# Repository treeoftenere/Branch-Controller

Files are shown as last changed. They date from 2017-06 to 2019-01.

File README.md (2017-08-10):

# Branch-Controller

The branch controllers are running on STM32 Bluepill boards with a wiznet w5500 based ethernet module.

The branch controller depends on the following:
1. Arduino support for STM32F1  ** master? **
2. FastLED with support for STM32F1  ** Currently uses Tenere Branch **
3. Ethernet library, based on the teensy implementation with faster settings  ** master? **

## Arduino settings:
Board:  Generic STM32F103C
Upload Method:  JLink

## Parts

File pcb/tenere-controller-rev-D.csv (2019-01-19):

Part/Designator | Description | MPN | Quantity
C1,C2,C3,C4,C5,C6,C7,C8 | Cap 1206 100uF | GRM31CD80J107ME39L | 8
C9,C10 | Cap 0603 10uF | CL10A106MQ8NNNC | 2
C11,C12 | Cap 0603 0.1uF | CL10B104KO8NNNC | 2
J1,J2,J3,J4,J5,J6,J7,J8 | 4 pin connector | 43650-0400 | 8
J10 | 8 pin DIP switch | BPA08B | 1
R1,R2,R3,R4,R5,R6,R7,R8,R9,R10,R11,R12,R13,R14,R15,R16 | Resistor 0603 22R | RC0603JR-0733RL | 16
SW1 | Tact switch | 1-1825027-1 | 1
U1 | STM32 module | STM32 module | 1
U2,U3 | 8 bit line driver | 74HCT245PW,118 | 2
U4 | 3.3V LDO | LD1117S33TR | 1
U5 | Ethernet module | Ethernet module | 1

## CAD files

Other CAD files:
enclosure/VG-S05.dwg

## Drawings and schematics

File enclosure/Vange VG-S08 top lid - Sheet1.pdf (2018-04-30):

G | G
H | H

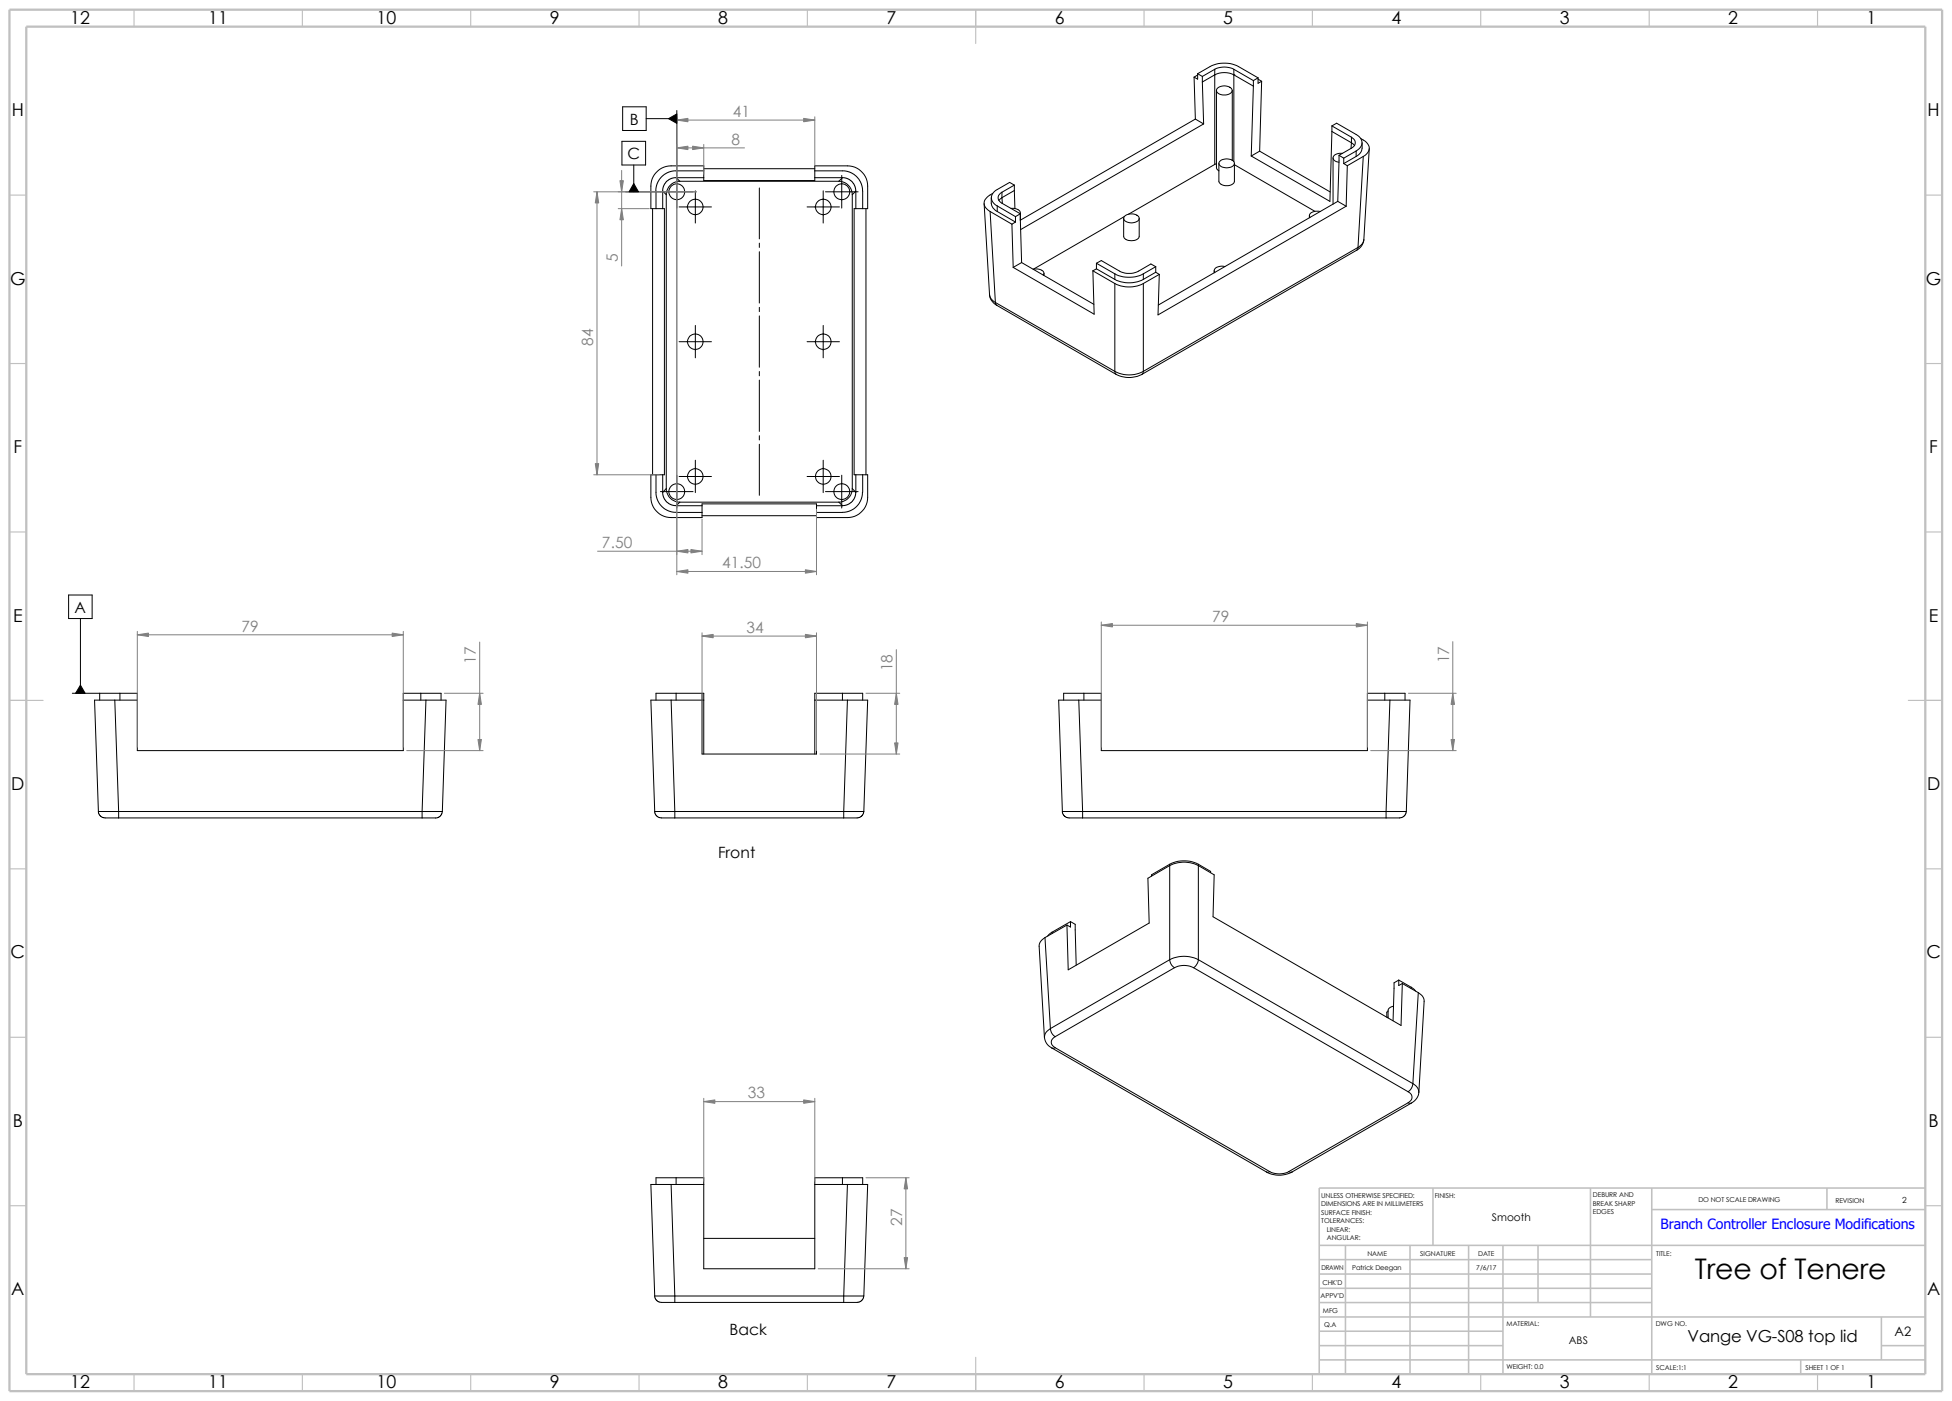
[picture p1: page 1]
Back; ABS; SHEET 1 OF 1; SCALE:1:1; MFG; FINISH:; EDGES; MATERIAL:; Smooth; REVISION; WEIGHT: 0.0; DEBURR AND; BREAK SHARP; Front

UNLESS OTHERWISE SPECIFIED:
DIMENSIONS ARE IN MILLIMETERS
SURFACE FINISH:
TOLERANCES:
LINEAR:
ANGULAR:

DO NOT SCALE DRAWING
Branch Controller Enclosure Modifications

NAME | SIGNATURE | DATE | TITLE: Tree of Tenere

DRAWN | Patrick Deegan | | 7/6/17

CHK'D

APPV'D

DWG NO.
Vange VG-S08 top lid

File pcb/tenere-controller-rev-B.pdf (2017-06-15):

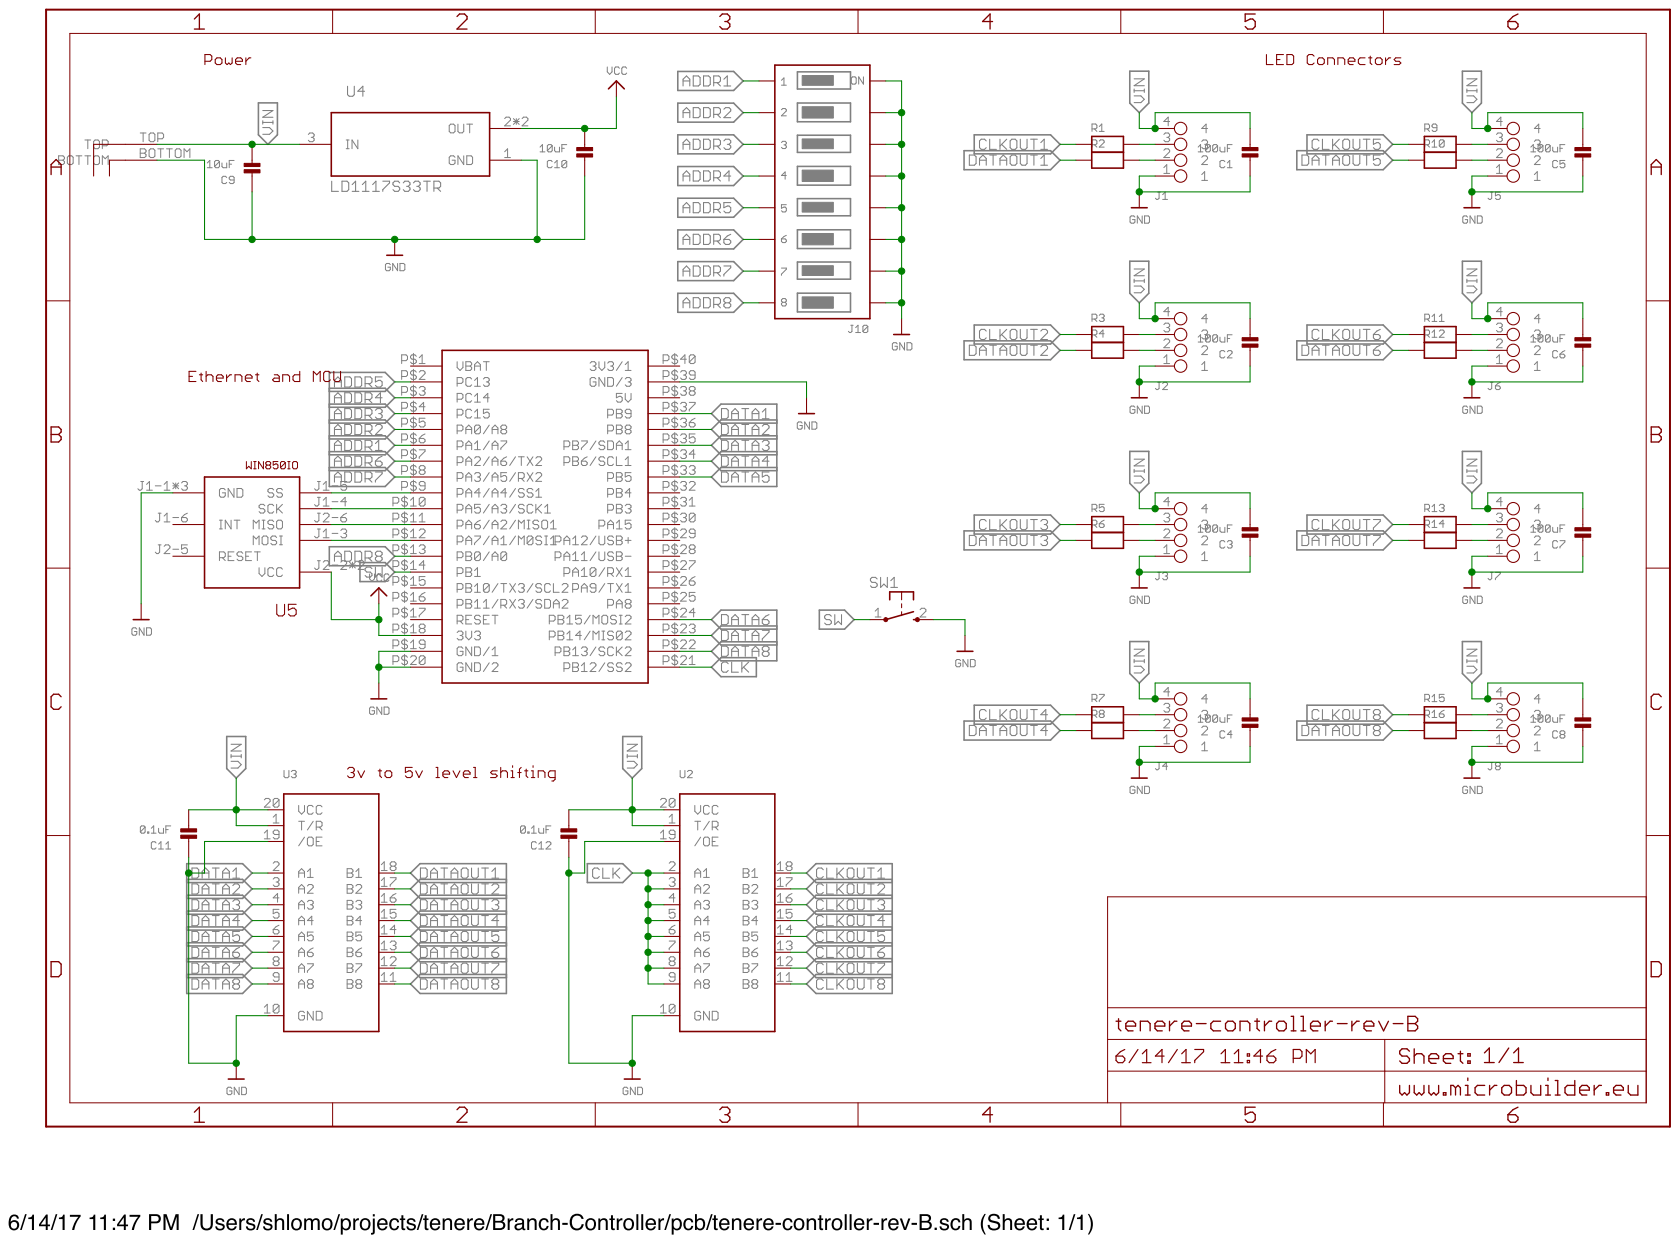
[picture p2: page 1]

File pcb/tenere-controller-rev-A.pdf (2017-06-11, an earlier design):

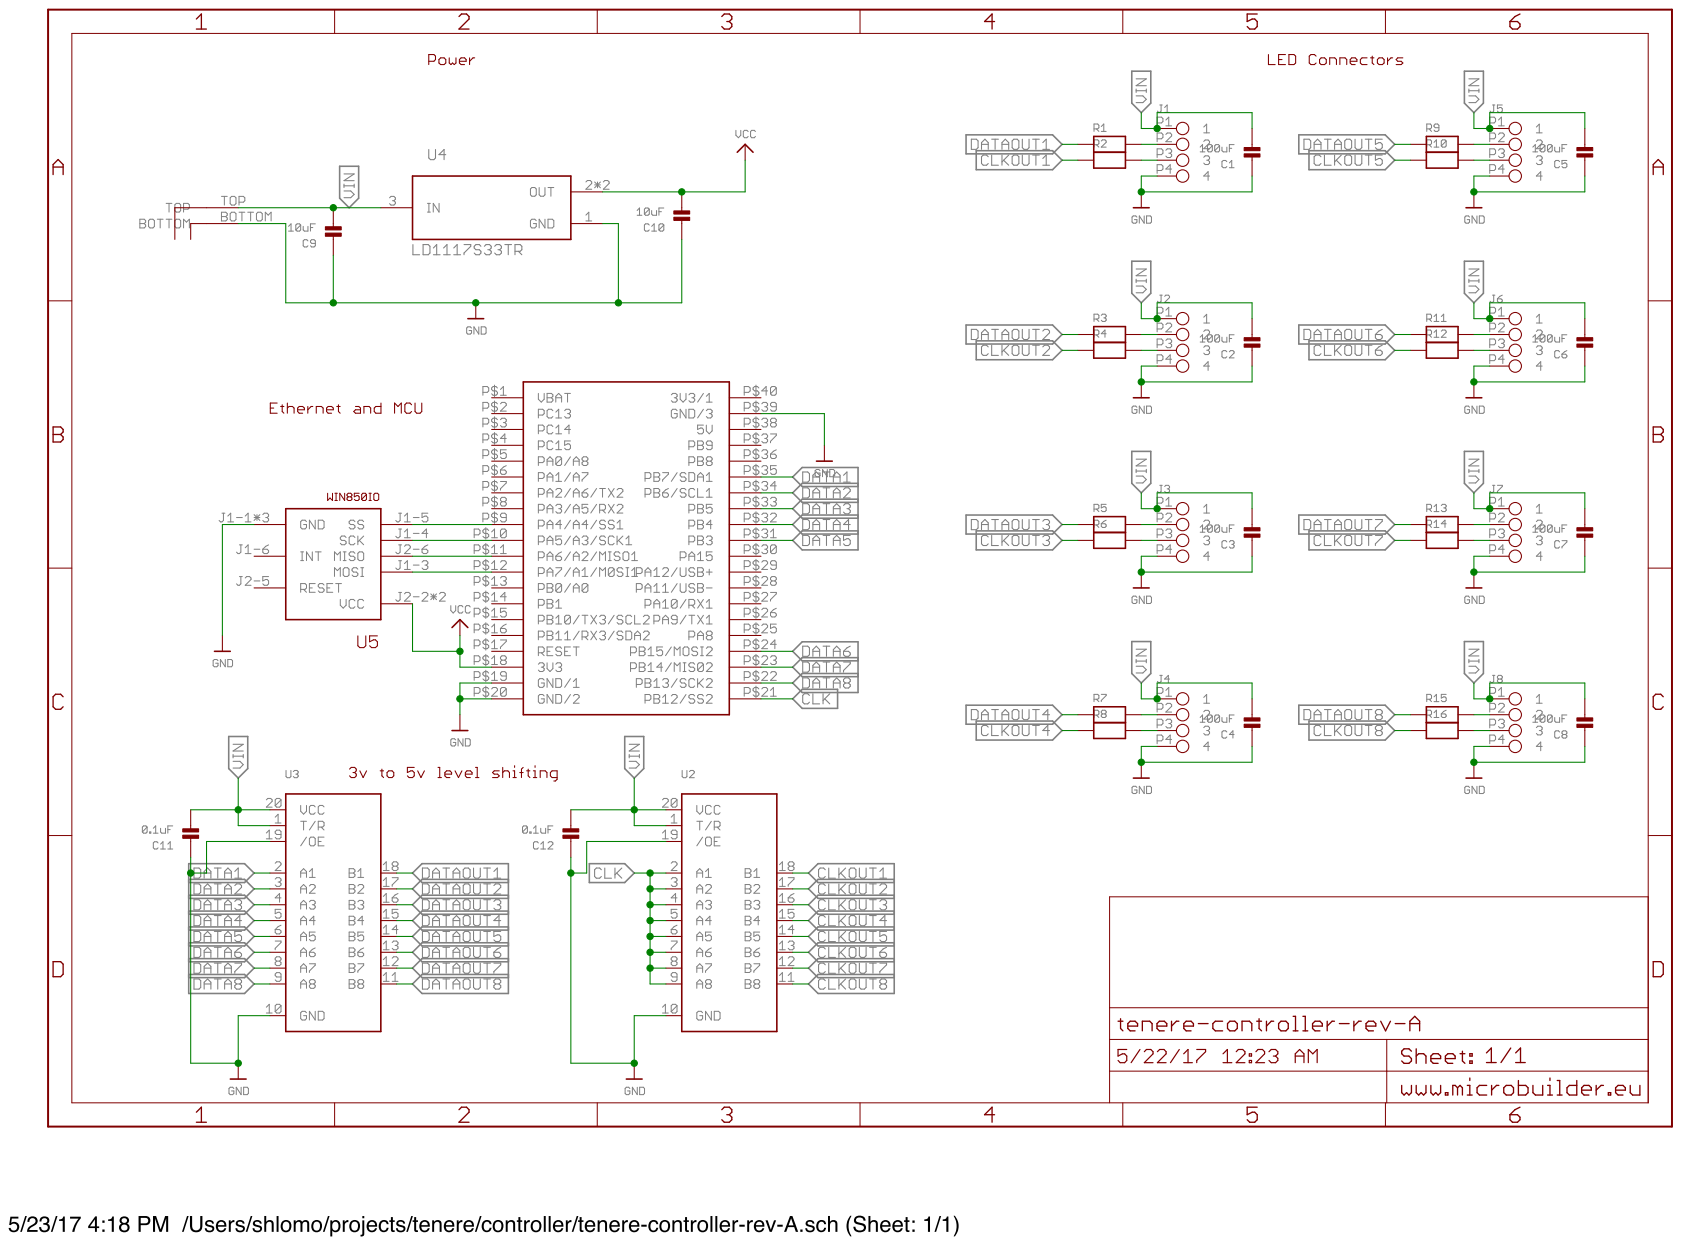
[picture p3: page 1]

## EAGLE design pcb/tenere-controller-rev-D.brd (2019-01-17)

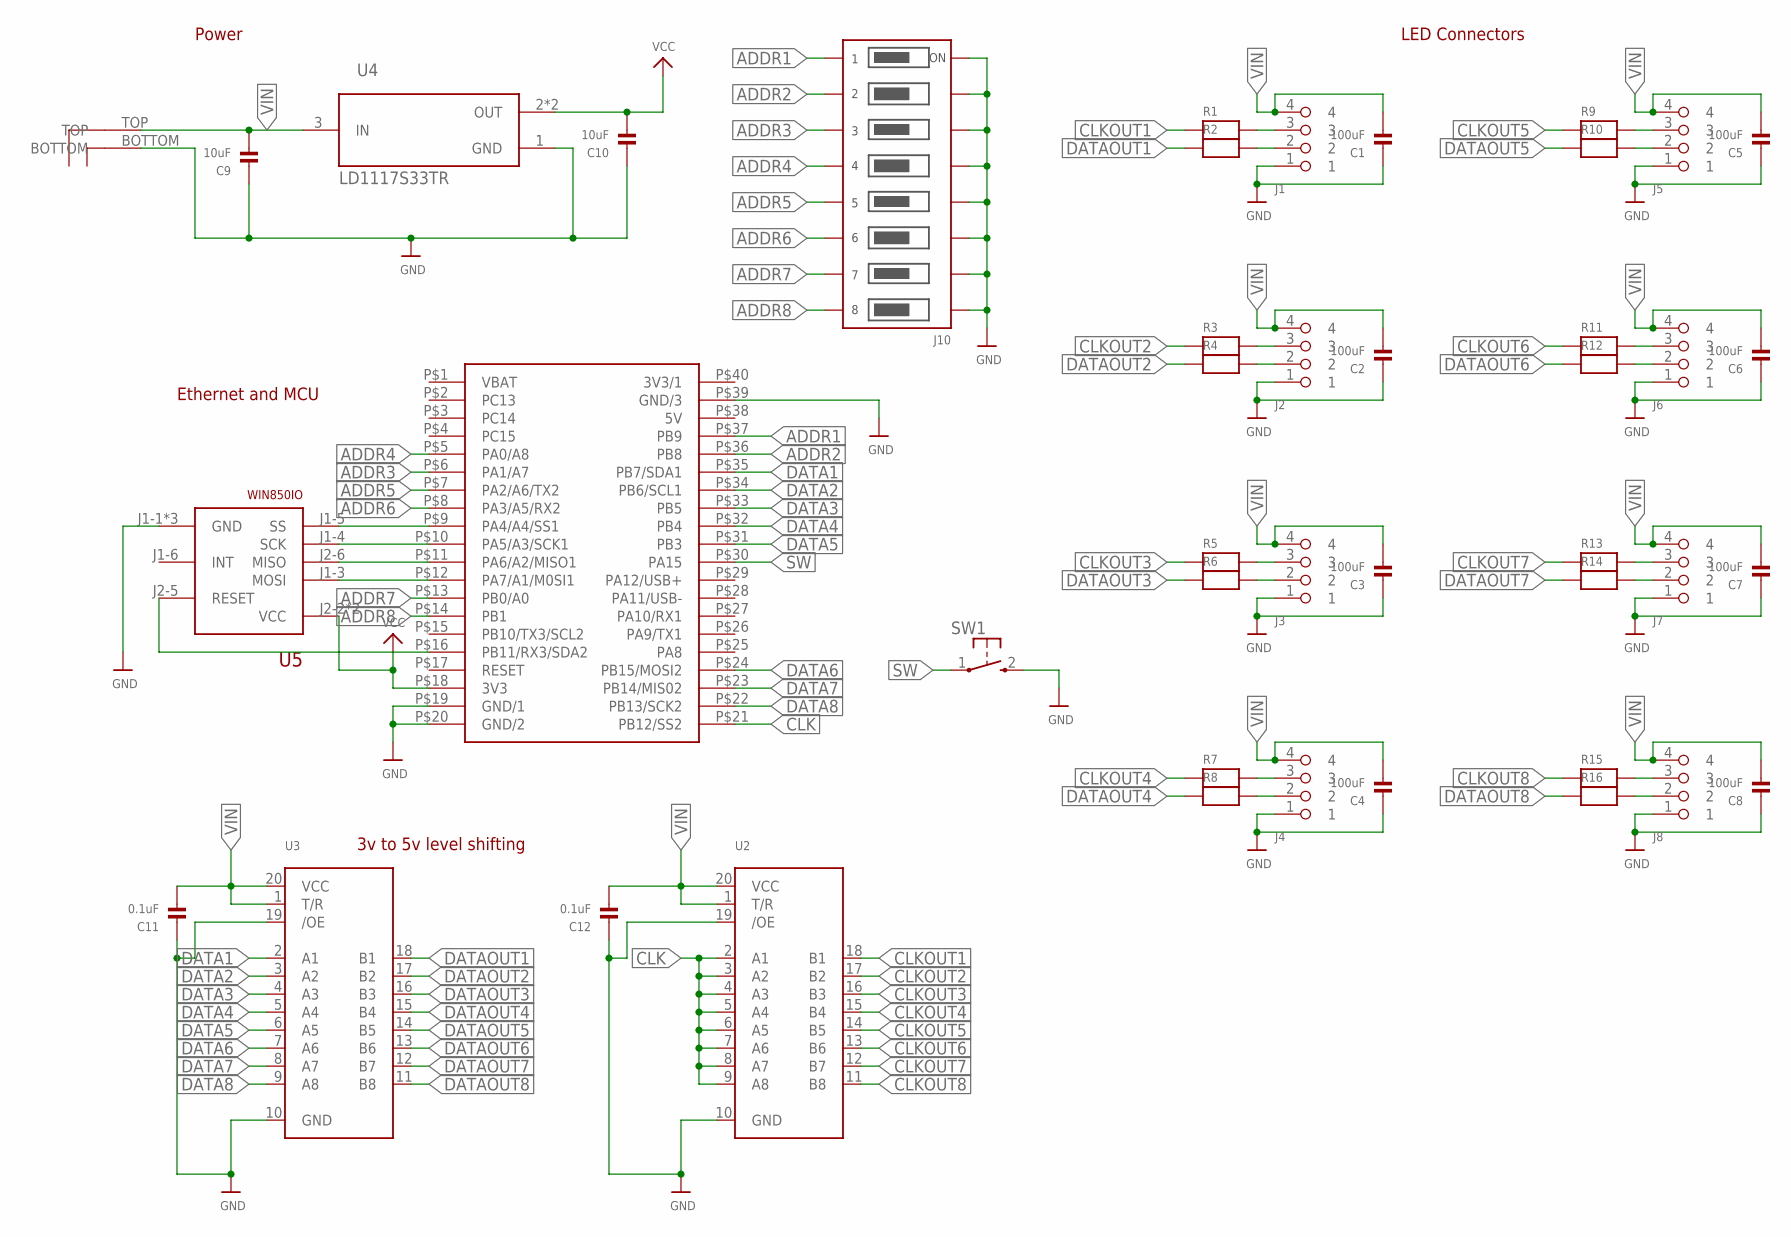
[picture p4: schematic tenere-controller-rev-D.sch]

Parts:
C1, C2, C3, C4, C5, C6, C7, C8: 100uF; 1206
C9, C10: 10uF; 0603
C11, C12: 0.1uF; 0603
J1, J2, J3, J4, J5, J6, J7, J8: MICROFIT3; 43650-0400
J9: POWERPOLE-2V; POWERPOLE_STACKED
J10: DIP-SWITCH-8PIN; BPA08B
R1, R2, R3, R4, R5, R6, R7, R8, R9, R10, R11, R12, R13, R14, R15, R16: RESISTOR0603; 0603
SW1: TACTILE-SWITCH-1825027; 1825027
U1: BLUEPILL; 40-DIP-BLUE-PIL
U2, U3: 74LCX245; TSSOP20
U4: LD1117S33TR; LD1117S33TR_SOT230P700X180-4N
U5: WIN850IO; WIZ850IO

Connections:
ADDR1: J10.1' (1B), U1.P$37 (PB9)
ADDR2: J10.2' (2B), U1.P$36 (PB8)
ADDR3: J10.3' (3B), U1.P$6 (PA1/A7)
ADDR4: J10.4' (4B), U1.P$5 (PA0/A8)
ADDR5: J10.5' (5B), U1.P$7 (PA2/A6/TX2)
ADDR6: J10.6' (6B), U1.P$8 (PA3/A5/RX2)
ADDR7: J10.7' (7B), U1.P$13 (PB0/A0)
ADDR8: J10.8' (8B), U1.P$14 (PB1)
CLK: U1.P$21 (PB12/SS2), U2.2 (A1), U2.3 (A2), U2.4 (A3), U2.5 (A4), U2.6 (A5), U2.7 (A6), U2.8 (A7), U2.9 (A8)
CLKOUT1: R1.1, U2.18 (B1)
CLKOUT2: R3.1, U2.17 (B2)
CLKOUT3: R5.1, U2.16 (B3)
CLKOUT4: R7.1, U2.15 (B4)
CLKOUT5: R9.1, U2.14 (B5)
CLKOUT6: R11.1, U2.13 (B6)
CLKOUT7: R13.1, U2.12 (B7)
CLKOUT8: R15.1, U2.11 (B8)
DATA1: U1.P$35 (PB7/SDA1), U3.2 (A1)
DATA2: U1.P$34 (PB6/SCL1), U3.3 (A2)
DATA3: U1.P$33 (PB5), U3.4 (A3)
DATA4: U1.P$32 (PB4), U3.5 (A4)
DATA5: U1.P$31 (PB3), U3.6 (A5)
DATA6: U1.P$24 (PB15/MOSI2), U3.7 (A6)
DATA7: U1.P$23 (PB14/MIS02), U3.8 (A7)
DATA8: U1.P$22 (PB13/SCK2), U3.9 (A8)
DATAOUT1: R2.1, U3.18 (B1)
DATAOUT2: R4.1, U3.17 (B2)
DATAOUT3: R6.1, U3.16 (B3)
DATAOUT4: R8.1, U3.15 (B4)
DATAOUT5: R10.1, U3.14 (B5)
DATAOUT6: R12.1, U3.13 (B6)
DATAOUT7: R14.1, U3.12 (B7)
DATAOUT8: R16.1, U3.11 (B8)
GND: C1.1, C2.1, C3.1, C4.1, C5.1, C6.1, C7.1, C8.1, C9.1, C10.1, C11.1, C12.1, J1.1, J2.1, J3.1, J4.1, J5.1, J6.1, J7.1, J8.1, J9.BOTTOM, J10.1 (1A), J10.2 (2A), J10.3 (3A), J10.4 (4A), J10.5 (5A), J10.6 (6A), J10.7 (7A), J10.8 (8A), SW1.2 (3), U1.P$19 (GND/1), U1.P$20 (GND/2), U1.P$39 (GND/3), U2.10 (GND), U2.19 (/OE), U3.10 (GND), U3.19 (/OE), U4.1 (GND), U5.J1-1 (GND), U5.J1-2 (GND), U5.J2-1 (GND)
unnamed: U1.P$9 (PA4/A4/SS1), U5.J1-5 (SS)
unnamed: U1.P$10 (PA5/A3/SCK1), U5.J1-4 (SCK)
unnamed: U1.P$11 (PA6/A2/MISO1), U5.J2-6 (MISO)
unnamed: U1.P$12 (PA7/A1/M0SI1), U5.J1-3 (MOSI)
unnamed: J1.3, R1.2
unnamed: J1.2, R2.2
unnamed: J2.3, R3.2
unnamed: J2.2, R4.2
unnamed: J3.3, R5.2
unnamed: J3.2, R6.2
unnamed: J4.3, R7.2
unnamed: J4.2, R8.2
unnamed: J5.3, R9.2
unnamed: J5.2, R10.2
unnamed: J6.3, R11.2
unnamed: J6.2, R12.2
unnamed: J7.3, R13.2
unnamed: J7.2, R14.2
unnamed: J8.3, R15.2
unnamed: J8.2, R16.2
unnamed: U1.P$16 (PB11/RX3/SDA2), U5.J2-5 (RESET)
SW: SW1.1, U1.P$30 (PA15)
VCC: C10.2, U1.P$18 (3V3), U4.2 (OUT), U4.4 (OUT), U5.J2-2 (VCC), U5.J2-3 (VCC)
VIN: C1.2, C2.2, C3.2, C4.2, C5.2, C6.2, C7.2, C8.2, C9.2, C11.2, C12.2, J1.4, J2.4, J3.4, J4.4, J5.4, J6.4, J7.4, J8.4, J9.TOP, U2.1 (T/R), U2.20 (VCC), U3.1 (T/R), U3.20 (VCC), U4.3 (IN)

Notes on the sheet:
LED Connectors
Power
Ethernet and MCU
3v to 5v level shifting

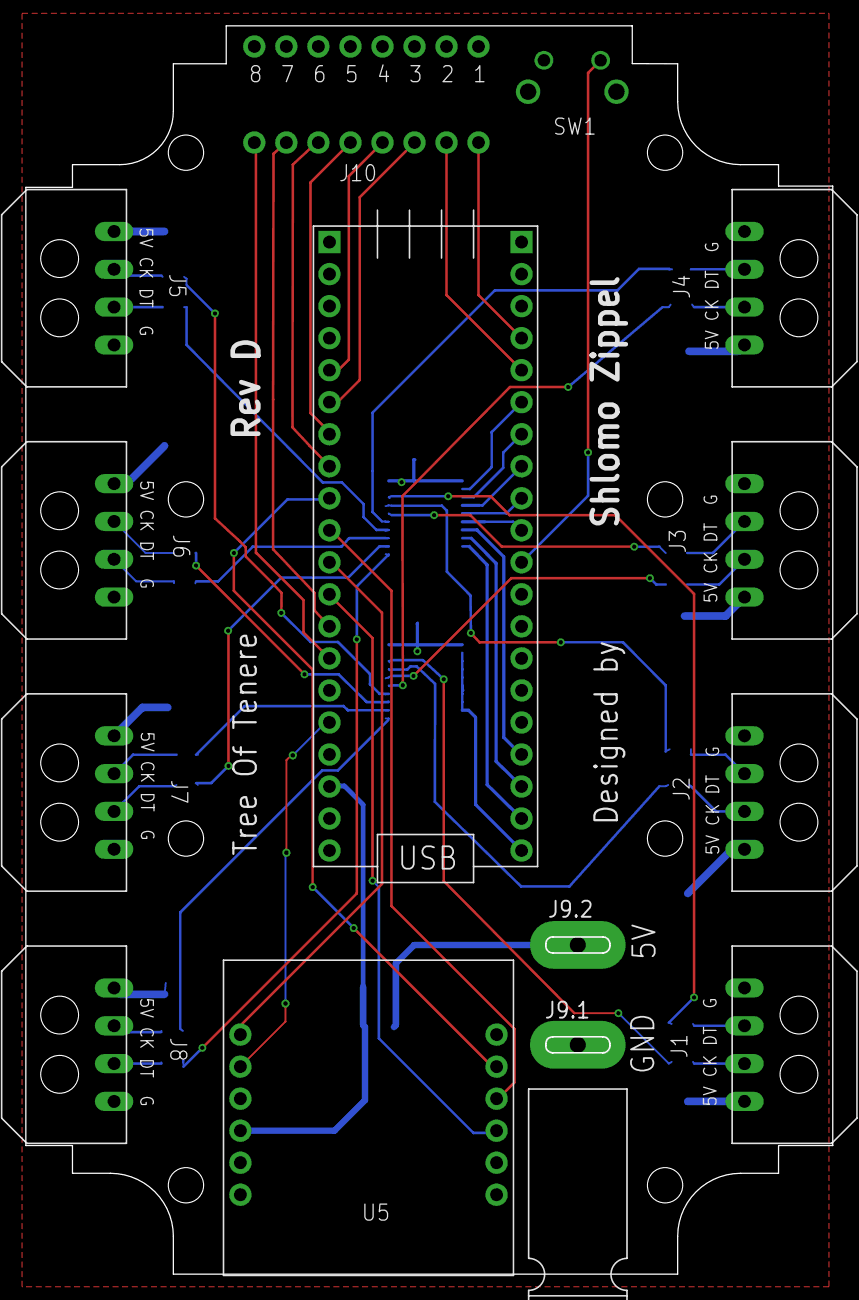
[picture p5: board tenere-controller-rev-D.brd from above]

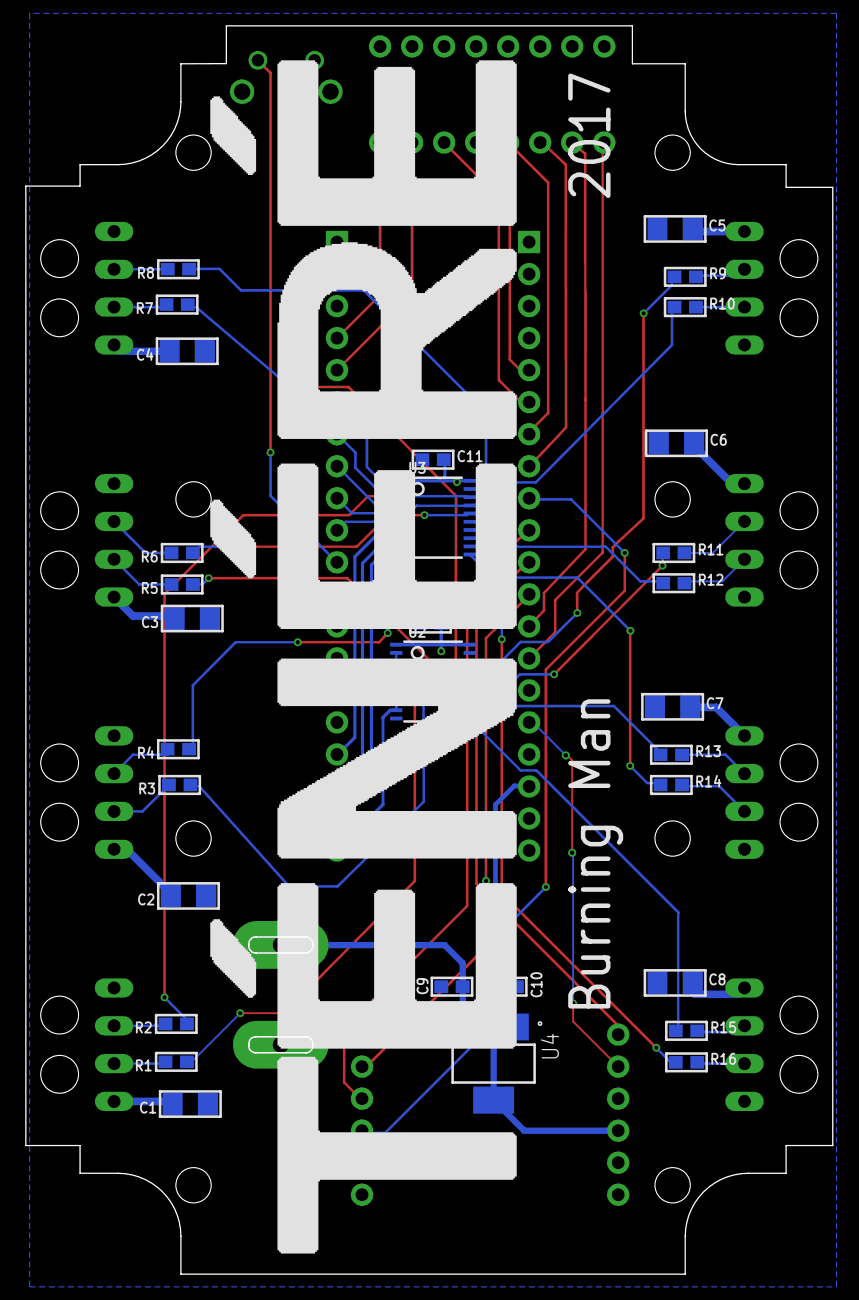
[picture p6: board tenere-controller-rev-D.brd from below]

Board: 2 copper layers, 64.0 x 99.0 mm, 45 parts (31 on the bottom side), 58 nets.

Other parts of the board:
U$15: 105*65

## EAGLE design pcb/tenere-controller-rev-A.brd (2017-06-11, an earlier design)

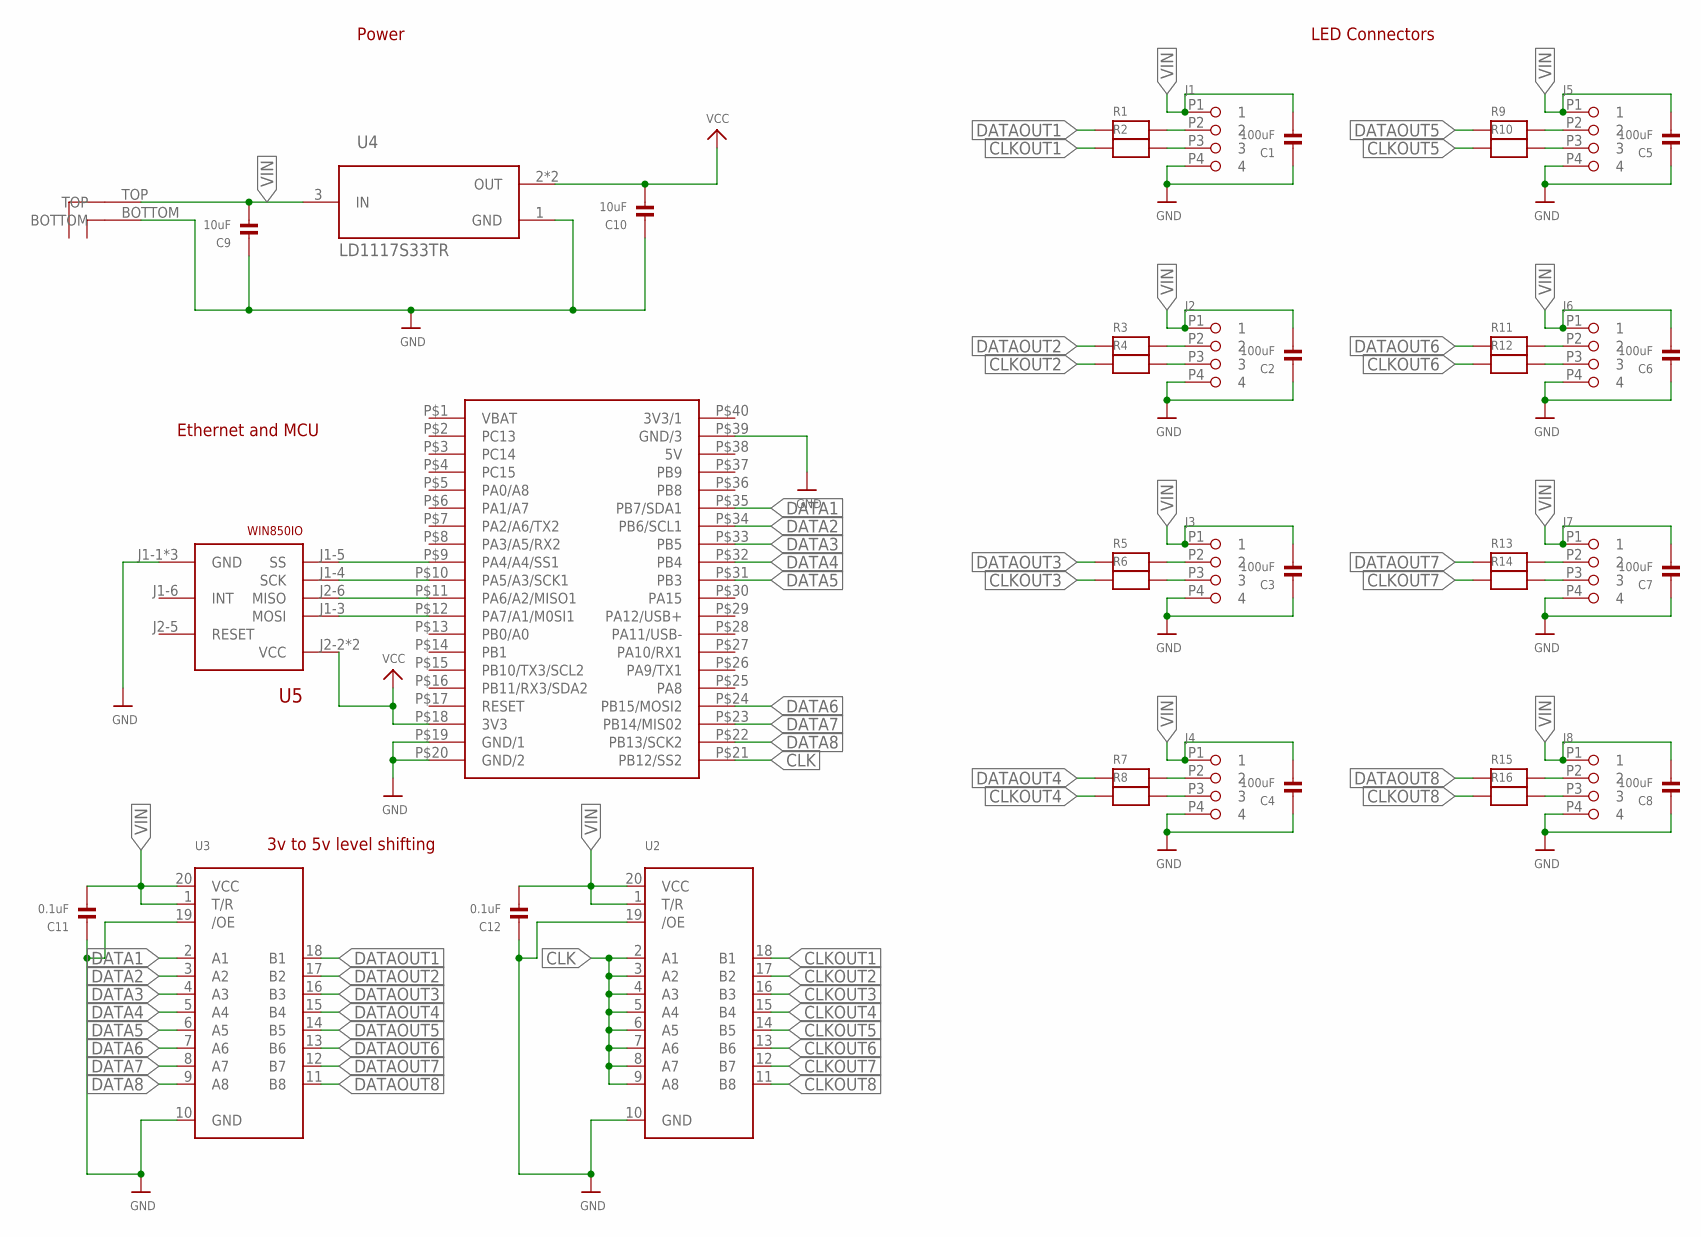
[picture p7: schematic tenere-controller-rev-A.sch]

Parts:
C1, C2, C3, C4, C5, C6, C7, C8: 100uF; 1206
C9, C10: 10uF; 0603
C11, C12: 0.1uF; 0603
J1, J2, J3, J4, J5, J6, J7, J8: JST-XH-4P-SODE; JST-XH-BS4P
J9: POWERPOLE-2V; POWERPOLE_STACKED
R1, R2, R3, R4, R5, R6, R7, R8, R9, R10, R11, R12, R13, R14, R15, R16: RESISTOR0603; 0603
U1: BLUEPILL; 40-DIP-BLUE-PIL
U2, U3: 74LCX245; TSSOP20
U4: LD1117S33TR; LD1117S33TR_SOT230P700X180-4N
U5: WIN850IO; WIZ850IO

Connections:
CLK: U1.P$21 (PB12/SS2), U2.2 (A1), U2.3 (A2), U2.4 (A3), U2.5 (A4), U2.6 (A5), U2.7 (A6), U2.8 (A7), U2.9 (A8)
CLKOUT1: R2.1, U2.18 (B1)
CLKOUT2: R4.1, U2.17 (B2)
CLKOUT3: R6.1, U2.16 (B3)
CLKOUT4: R8.1, U2.15 (B4)
CLKOUT5: R10.1, U2.14 (B5)
CLKOUT6: R12.1, U2.13 (B6)
CLKOUT7: R14.1, U2.12 (B7)
CLKOUT8: R16.1, U2.11 (B8)
DATA1: U1.P$35 (PB7/SDA1), U3.2 (A1)
DATA2: U1.P$34 (PB6/SCL1), U3.3 (A2)
DATA3: U1.P$33 (PB5), U3.4 (A3)
DATA4: U1.P$32 (PB4), U3.5 (A4)
DATA5: U1.P$31 (PB3), U3.6 (A5)
DATA6: U1.P$24 (PB15/MOSI2), U3.7 (A6)
DATA7: U1.P$23 (PB14/MIS02), U3.8 (A7)
DATA8: U1.P$22 (PB13/SCK2), U3.9 (A8)
DATAOUT1: R1.1, U3.18 (B1)
DATAOUT2: R3.1, U3.17 (B2)
DATAOUT3: R5.1, U3.16 (B3)
DATAOUT4: R7.1, U3.15 (B4)
DATAOUT5: R9.1, U3.14 (B5)
DATAOUT6: R11.1, U3.13 (B6)
DATAOUT7: R13.1, U3.12 (B7)
DATAOUT8: R15.1, U3.11 (B8)
GND: C1.1, C2.1, C3.1, C4.1, C5.1, C6.1, C7.1, C8.1, C9.1, C10.1, C11.1, C12.1, J1.P4 (4), J2.P4 (4), J3.P4 (4), J4.P4 (4), J5.P4 (4), J6.P4 (4), J7.P4 (4), J8.P4 (4), J9.BOTTOM, U1.P$19 (GND/1), U1.P$20 (GND/2), U1.P$39 (GND/3), U2.10 (GND), U2.19 (/OE), U3.10 (GND), U3.19 (/OE), U4.1 (GND), U5.J1-1 (GND), U5.J1-2 (GND), U5.J2-1 (GND)
unnamed: U1.P$9 (PA4/A4/SS1), U5.J1-5 (SS)
unnamed: U1.P$10 (PA5/A3/SCK1), U5.J1-4 (SCK)
unnamed: U1.P$11 (PA6/A2/MISO1), U5.J2-6 (MISO)
unnamed: U1.P$12 (PA7/A1/M0SI1), U5.J1-3 (MOSI)
unnamed: J1.P2 (2), R1.2
unnamed: J1.P3 (3), R2.2
unnamed: J2.P2 (2), R3.2
unnamed: J2.P3 (3), R4.2
unnamed: J3.P2 (2), R5.2
unnamed: J3.P3 (3), R6.2
unnamed: J4.P2 (2), R7.2
unnamed: J4.P3 (3), R8.2
unnamed: J5.P2 (2), R9.2
unnamed: J5.P3 (3), R10.2
unnamed: J6.P2 (2), R11.2
unnamed: J6.P3 (3), R12.2
unnamed: J7.P2 (2), R13.2
unnamed: J7.P3 (3), R14.2
unnamed: J8.P2 (2), R15.2
unnamed: J8.P3 (3), R16.2
VCC: C10.2, U1.P$18 (3V3), U4.2 (OUT), U4.4 (OUT), U5.J2-2 (VCC), U5.J2-3 (VCC)
VIN: C1.2, C2.2, C3.2, C4.2, C5.2, C6.2, C7.2, C8.2, C9.2, C11.2, C12.2, J1.P1 (1), J2.P1 (1), J3.P1 (1), J4.P1 (1), J5.P1 (1), J6.P1 (1), J7.P1 (1), J8.P1 (1), J9.TOP, U2.1 (T/R), U2.20 (VCC), U3.1 (T/R), U3.20 (VCC), U4.3 (IN)

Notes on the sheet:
LED Connectors
Power
Ethernet and MCU
3v to 5v level shifting

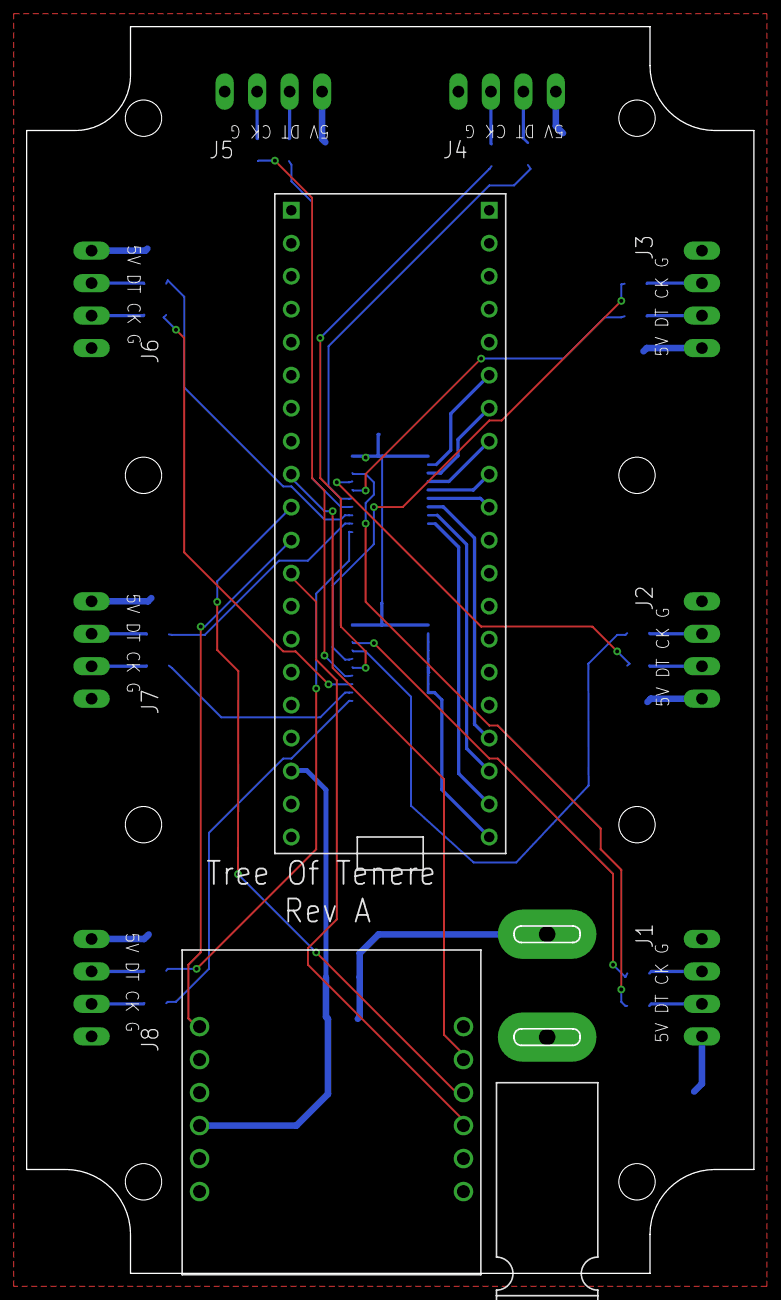
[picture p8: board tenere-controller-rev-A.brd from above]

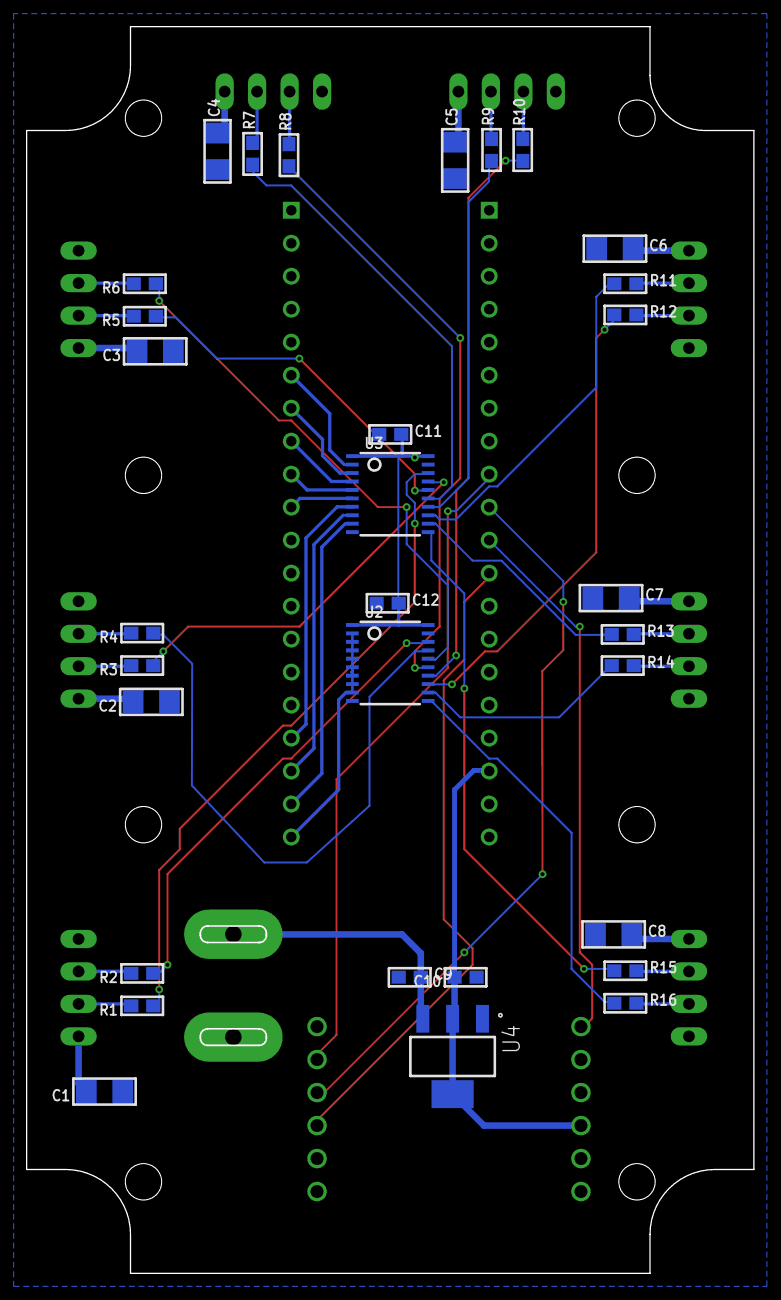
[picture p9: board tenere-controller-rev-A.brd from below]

Board: 2 copper layers, 56.0 x 96.0 mm, 43 parts (31 on the bottom side), 48 nets.

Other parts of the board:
U$15: 105*65

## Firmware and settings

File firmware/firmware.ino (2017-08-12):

#include <SPI.h>
#include <Ethernet.h>
#include <FastLED.h>
#include <EEPROM.h>
#include "button.h"

#define LEDS_PER_CHANNEL    105
#define NUM_CHANNELS        8
#define NUM_LEDS            (NUM_CHANNELS * LEDS_PER_CHANNEL)
#define COLOR_ORDER         BGR
#define SPI_RATE            DATA_RATE_MHZ(4)
#define UDP_RX_BUFFER_SIZE  8192
#define UDP_PORT_NUMBER     1337

#define PARALLEL_OUTPUT
#define PLAYA_MODE

//-------------------------------------------------------------------------------------------
// Pin mappings
//-------------------------------------------------------------------------------------------

//#define REVB
#define REVC

#ifdef REVB
uint8_t dip_switch_pins[] = {PA0, PA1, PA2, PA3, PB0};
#define SWITCH_PIN  PB1
#endif 

#ifdef REVC
uint8_t dip_switch_pins[] = {PB9, PB8, PA1, PA0, PA2, PA3, PB0, PB1};
#define SWITCH_PIN  PA15
#endif

#define FPS_PIN         PA0
#define CLOCK_PIN       PB12
#define ETHERNET_CS_PIN PA4
#define INDICATOR_PIN   PC13

#define ARRAY_SIZE(A) (sizeof(A) / sizeof((A)[0]))

CRGB leds[NUM_CHANNELS][LEDS_PER_CHANNEL];

typedef struct _opc_header_t {
  uint8_t channel;
  uint8_t command;
  uint8_t datalen_h;
  uint8_t datalen_l;
  uint8_t data[];
} opc_header_t;

EthernetUDP Udp;
char packet_buffer[UDP_RX_BUFFER_SIZE]; 

FastPin<FPS_PIN> fps;

Button sw(SWITCH_PIN);

uint32_t last_packet_time = 0;
uint8_t brightness = 0;

//-------------------------------------------------------------------------------------------
// IP & Mac address
//-------------------------------------------------------------------------------------------

// this default mac seems to work well as a template, lets just replace a single
// byte based on controller address
byte mac[] = {
  0xDE, 0xAD, 0xBE, 0xEF, 0xFE, 0xED
};

uint8_t get_address() {
    uint8_t result = 0;
    for (int i = 0; i < ARRAY_SIZE(dip_switch_pins); i++) {
        result = result | !digitalRead(dip_switch_pins[i]) << i;
    }
    return result;
}


//-------------------------------------------------------------------------------------------
// Test patterns
//-------------------------------------------------------------------------------------------

void network() {
  // clear the buffer if we didn't receive a packet for a while
  int32_t delta = millis() - last_packet_time - 10000;
  if (delta > 10000) {
    brightness = 0;
  } else if (delta > 0) {
    brightness = map(delta, 0, 10000, 255, 0);
  } else {
    brightness = qadd8(brightness, 5);
  }

  FastLED.setBrightness(brightness);
}

void rainbow() {
    static uint8_t hue=0;
    fill_rainbow((CRGB*)leds, NUM_LEDS, ++hue, 10);  
}

void fullwhite() {
    fill_solid((CRGB*)leds, NUM_LEDS, CRGB::White);  
}

typedef void (*SimplePatternList[])();
uint8_t g_current_pattern = 0;

SimplePatternList patterns = {
  network,
  rainbow,
  //fullwhite,
};

void render() {
  (patterns)[g_current_pattern]();
  FastLED.delay(1000/120);
}

void next_pattern()
{
  g_current_pattern = (g_current_pattern + 1) % ARRAY_SIZE( patterns);
  fill_solid((CRGB*)leds, NUM_LEDS, CRGB::Black);
  FastLED.setBrightness(255);
}


//-------------------------------------------------------------------------------------------
// Network code
//-------------------------------------------------------------------------------------------

bool got_a_packet = false;

void network_connect() {
  Ethernet.init(ETHERNET_CS_PIN);
  Ethernet.softReset();

  // attempt to read stored address first
  uint8_t addr;
  addr = EEPROM.read(0);
  if (255 == addr) {
      addr = get_address();
  }
  
  mac[2] = addr;
  IPAddress ip_addr(192, 168, 1, addr);
  Ethernet.begin(mac, ip_addr);
  Udp.begin(UDP_PORT_NUMBER);
}

void network_poll() {
  int packet_size = Udp.parsePacket();
  static int remaining = 0;
  if (packet_size > 0) {
    got_a_packet = true;
    last_packet_time = millis();
    FastLED.setBrightness(255);

    // force us into network mode if we receive a packet
    g_current_pattern = 0;
    
    
    remaining += Udp.read(packet_buffer+remaining,UDP_RX_BUFFER_SIZE);
    opc_header_t * header = (opc_header_t *)packet_buffer;
    while (remaining > 4) {
      fps.toggle();
      uint16_t data_size = header->datalen_h << 8 | header->datalen_l;
      uint16_t offset = (int)header->channel * LEDS_PER_CHANNEL * 3;
      memcpy8((uint8_t *) leds + offset, header->data, min(data_size, remaining-4));
      remaining -= (data_size + 4);
      header = (opc_header_t *) (packet_buffer+data_size+4);

      // intermediate render if we have multiple frames in this packet
      if (remaining > 4) {
        render();
      }
    }
  }
}

//-------------------------------------------------------------------------------------------
// Button handlers
//-------------------------------------------------------------------------------------------

void button_press() {
  // Only switch modes on playa if we don't have network activity
  #ifdef PLAYA_MODE
  if (!got_a_packet)
  #endif
    next_pattern();
}

void button_hold() {
  EEPROM.write(0, get_address());  
  network_connect();

  digitalWrite(INDICATOR_PIN, LOW);
  delay(250);
  digitalWrite(INDICATOR_PIN, HIGH);
  delay(250);
  digitalWrite(INDICATOR_PIN, LOW);
  delay(250);
  digitalWrite(INDICATOR_PIN, HIGH);
}

void setup() {
  #ifdef REVB
    #ifdef PARALLEL_OUTPUT
      FastLED.addLeds<TENERE_REVB, CLOCK_PIN, COLOR_ORDER, SPI_RATE>(leds, LEDS_PER_CHANNEL);
    #else
      FastLED.addLeds<APA102, PB13, CLOCK_PIN, COLOR_ORDER, SPI_RATE>(leds[0],LEDS_PER_CHANNEL);
      FastLED.addLeds<APA102, PB14, CLOCK_PIN, COLOR_ORDER, SPI_RATE>(leds[1],LEDS_PER_CHANNEL);
      FastLED.addLeds<APA102, PB15, CLOCK_PIN, COLOR_ORDER, SPI_RATE>(leds[2],LEDS_PER_CHANNEL);
      FastLED.addLeds<APA102, PB5, CLOCK_PIN, COLOR_ORDER, SPI_RATE>(leds[3],LEDS_PER_CHANNEL);
      FastLED.addLeds<APA102, PB6, CLOCK_PIN, COLOR_ORDER, SPI_RATE>(leds[4],LEDS_PER_CHANNEL);
      FastLED.addLeds<APA102, PB7, CLOCK_PIN, COLOR_ORDER, SPI_RATE>(leds[5],LEDS_PER_CHANNEL);
      FastLED.addLeds<APA102, PB8, CLOCK_PIN, COLOR_ORDER, SPI_RATE>(leds[6],LEDS_PER_CHANNEL);
      FastLED.addLeds<APA102, PB9, CLOCK_PIN, COLOR_ORDER, SPI_RATE>(leds[7],LEDS_PER_CHANNEL);
    #endif
  #endif

  #ifdef REVC
    #ifdef PARALLEL_OUTPUT
      FastLED.addLeds<TENERE_REVC, CLOCK_PIN, COLOR_ORDER, SPI_RATE>((CRGB *)leds, LEDS_PER_CHANNEL);
    #else
      FastLED.addLeds<APA102, PB7, CLOCK_PIN, COLOR_ORDER, SPI_RATE>(leds[0],LEDS_PER_CHANNEL);
      FastLED.addLeds<APA102, PB6, CLOCK_PIN, COLOR_ORDER, SPI_RATE>(leds[1],LEDS_PER_CHANNEL);
      FastLED.addLeds<APA102, PB5, CLOCK_PIN, COLOR_ORDER, SPI_RATE>(leds[2],LEDS_PER_CHANNEL);
      FastLED.addLeds<APA102, PB4, CLOCK_PIN, COLOR_ORDER, SPI_RATE>(leds[3],LEDS_PER_CHANNEL);
      FastLED.addLeds<APA102, PB3, CLOCK_PIN, COLOR_ORDER, SPI_RATE>(leds[4],LEDS_PER_CHANNEL);
      FastLED.addLeds<APA102, PB15, CLOCK_PIN, COLOR_ORDER, SPI_RATE>(leds[5],LEDS_PER_CHANNEL);
      FastLED.addLeds<APA102, PB14, CLOCK_PIN, COLOR_ORDER, SPI_RATE>(leds[6],LEDS_PER_CHANNEL);
      FastLED.addLeds<APA102, PB13, CLOCK_PIN, COLOR_ORDER, SPI_RATE>(leds[7],LEDS_PER_CHANNEL);
    #endif
  #endif
  
  FastLED.setBrightness(255);
  SPI.begin();

  // debug pin
  fps.setOutput();

  // ip address dip switch
   for (int i = 0; i < ARRAY_SIZE(dip_switch_pins); i++) {
       pinMode(dip_switch_pins[i], INPUT_PULLUP);
   }

   // indicator LED
   pinMode(INDICATOR_PIN, OUTPUT);
   digitalWrite(INDICATOR_PIN, HIGH);

   // wait a bit before connecting to ensure the switches are powered on
   delay(3000);
   network_connect();
}


void loop() {
  sw.poll(button_press, button_hold);

  network_poll();
  
  render();  
}

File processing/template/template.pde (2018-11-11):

// This is an empty Processing sketch with support for Fadecandy.

OPC opc;

void setup()
{
  size(600, 300);
  opc = new OPC(this, "127.0.0.1", 1337, 8);

  // Set up your LED mapping here
  opc.ledStrip(0, 0, 10, width * 1/8, height * 1/9, height/9, 0, false);
  opc.ledStrip(1, 0, 100, width * 1/8, height * 2/9, height/9, 0, false);
  opc.ledStrip(2, 0, 10, width * 1/8, height * 3/9, height/9, 0, false);
  opc.ledStrip(3, 0, 100, width * 1/8, height * 4/9, height/9, 0, false);
  opc.ledStrip(4, 0, 10, width * 1/8, height * 5/9, height/9, 0, false);
  opc.ledStrip(5, 0, 100, width * 1/8, height * 6/9, height/9, 0, false);
  opc.ledStrip(6, 0, 100, width * 1/8, height * 7/9, height/9, 0, false);
  opc.ledStrip(7, 0, 100, width * 1/8, height * 8/9, height/9, 0, false);
  
}

void draw()
{
  background(0);

  // Draw each frame here
}

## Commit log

2017-06-11 Added initial pcb, mechanical, firmware
    [VG-S05.dwg, tenere-controller-rev-A.brd, tenere-controller-rev-A.sch]
2017-06-15 controller rev b pcb
    [tenere-controller-rev-B.brd, tenere-controller-rev-B.sch]
2017-06-15 Minor change to one of the connectors
    [tenere-controller-rev-B.brd]
2017-06-15 Silkscreen fixes
    [tenere-controller-rev-B.brd]
2017-06-15 Minor fixes for oshpark drc
    [tenere-controller-rev-B.brd]
2017-06-25 Rev C
    [tenere-controller-rev-C.brd, tenere-controller-rev-C.csv, tenere-controller-rev-C.sch]
2017-08-10 Dependency version info. Arduino settings.
2019-01-17 Added Rev D PCB
    [tenere-controller-rev-D.brd, tenere-controller-rev-D.sch]
2019-01-19 Added BOM file for Rev D
    [tenere-controller-rev-D.csv]

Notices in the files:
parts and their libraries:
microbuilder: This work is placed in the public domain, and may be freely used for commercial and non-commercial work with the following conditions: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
